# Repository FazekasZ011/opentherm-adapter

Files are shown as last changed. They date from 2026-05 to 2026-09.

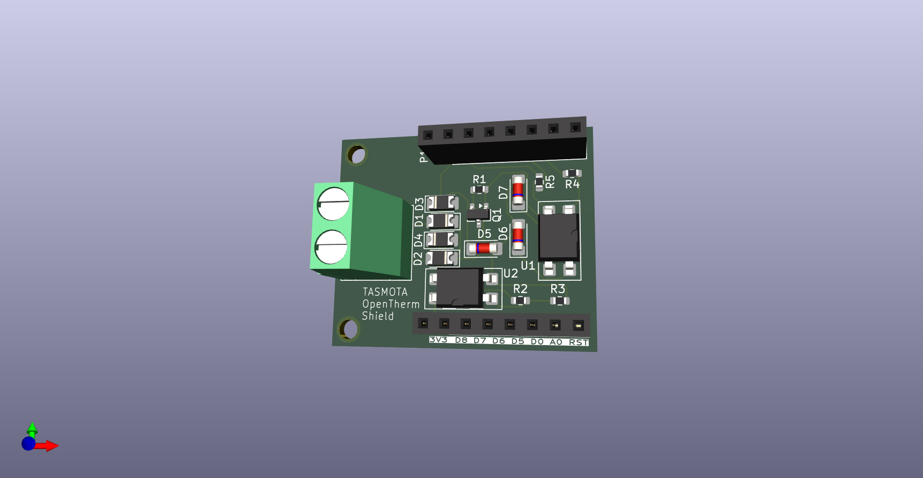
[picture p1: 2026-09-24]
KiCAD/opentherm shield.png

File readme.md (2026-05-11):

esphome - megvan
esphome builder kell még
esp-homebuildernél:
	- new device
	- new device setup
	- név bármi amit jónak találsz
- installation: 
	skip this step
	beállítod az eszközöd (esp8266)
	Install, majd cancel
	
létrejött az általad elnevezett XY.yaml egy kártyán látod az esphome felületén.

A kártyán válaszd az Edit-et.

Nagyon fontos:
az esp8266:
  board: esp01_1m eszköz helyére ezt írd: board: d1_mini

a captive_portal:
után ezt illeszd be:

# --- OPENTHERM ALAPBEÁLLÍTÁS ---
opentherm:
  in_pin: D2  # Wemos D2
  out_pin: D1 # Wemos D1

# --- SZENZOROK (Adatgyűjtés a kazánból) ---
sensor:
  - platform: opentherm
    t_boiler:
      name: "Kazán Előremenő Hőmérséklet"
    t_ret:
      name: "Visszatérő Hőmérséklet"
    
    # rel_mod_lvl helyett rel_mod_level-t kér:
    rel_mod_level: 
      name: "Kazán Aktuális Moduláció"
      unit_of_measurement: "%"
    
    # pressure helyett ch_pressure-t kér:
    ch_pressure: 
      name: "Rendszernyomás"
      unit_of_measurement: "bar"
      
    t_outside:
      name: "Kazán által érzékelt külső hőm"

# --- VEZÉRLÉS (Ezeket fogja a PID állítani a HA-ból) ---
number:
  - platform: opentherm
    # setpoint_temperature helyett t_set
    t_set:
      name: "Fűtési víz alapjel (CH Setpoint)"
      initial_value: 40
      min_value: 20
      max_value: 75
      step: 0.5
    
    # hot_water_setpoint_temperature helyett t_dhw_set
    t_dhw_set:
      name: "Melegvíz alapjel (DHW Setpoint)"
      initial_value: 45
      min_value: 35
      max_value: 65
      step: 1

# --- ÁLLAPOTJELZŐK (Diagnosztika) ---
binary_sensor:
  - platform: opentherm
    flame_on:
      name: "Gázláng"
    # central_heating_active helyett ch_active
    ch_active:
      name: "Fűtés aktív"
    # hot_water_active helyett dhw_active
    dhw_active:
      name: "Melegvíz készítés aktív"
    # fault helyett flame_fault vagy fault_indication (a logod flame_fault-ot sugall)
    flame_fault:
      name: "Kazán Hiba"
    diagnostic_indication:
      name: "Szerviz jelzés"

# --- KAPCSOLÓK ---
switch:
  - platform: opentherm
    ch_enable:
      name: "Fűtés Engedélyezése"
    dhw_enable:
      name: "Melegvíz Engedélyezése"

majd mentsd
utána a kártyán a 3 pöttynél válaszd az installt.
majd kábellel össze kell kötnöd a géped a wemossal.
válaszd a Plug into this computer-t
itt kiválasztod a COM-portot ahol az eszköz van. 
vársz és jó lesz.

Azt majd nézd meg, hogy a Secret nevű fájl létre jött-e mikor az esphomebuildert megcsináltad.

Ha megakadsz írj.

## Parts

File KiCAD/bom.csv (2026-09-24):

Designator | Footprint | Quantity | Value | LCSC Part #
D1, D2, D3, D4 | 1206 | 4 | 1N4148W
D5 | D_MiniMELF | 1 | BZV55B4V7
D6 | D_MiniMELF | 1 | BZV55B15
D7 | D_MiniMELF | 1 | BZV55B4V3
J1 | TerminalBlock_Phoenix_MKDS-1,5-2_1x02_P5.00mm_Horizontal | 1 | Screw_Terminal_01x02
P1, P2 | PinSocket_1x08_P2.54mm_Vertical | 2 | Conn_01x08_Pin
Q1 | SOT-23 | 1 | BC858
R1, R4 | 0603 | 2 | 330
R2 | 0603 | 1 | 220
R3 | 0603 | 1 | 100
R5 | 0603 | 1 | 1,5k
U1, U2 | DIP-4_W7.62mm_SMDSocket_SmallPads | 2 | PC817

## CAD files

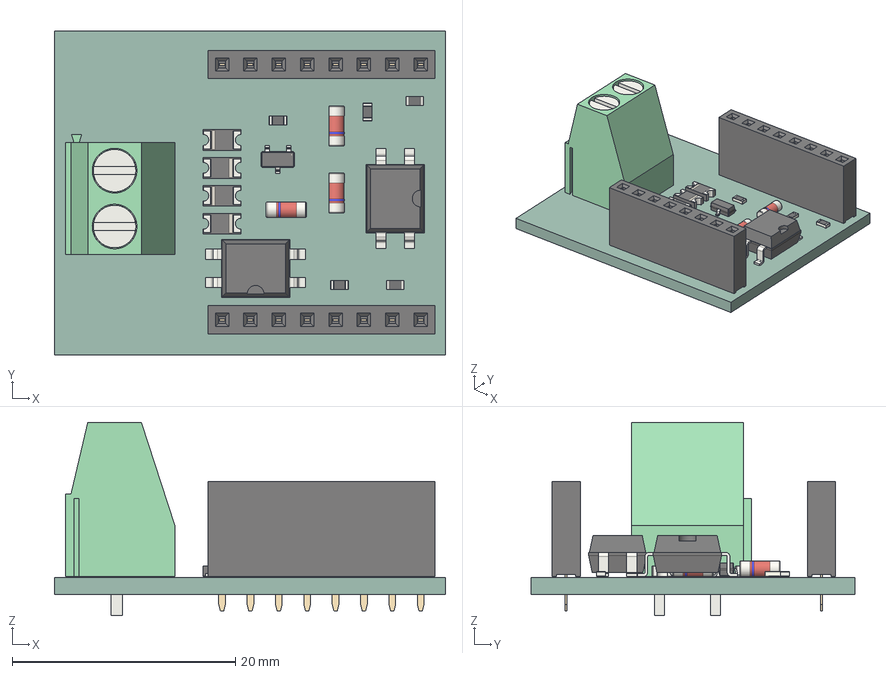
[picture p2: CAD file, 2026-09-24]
KiCAD/opentherm shield.step
35.0 x 29.0 x 17.3 mm
R_0603_1608Metric x 5
PinSocket_1x08_P2.54mm_Vertical x 2
DIP-4_W7.62mm_SMDSocket x 2
D_1206_3216Metric x 4
TerminalBlock_Phoenix_MKDS-1,5-2_1x02_P5.00mm_Horizontal
SOT-23
D_MiniMELF x 3
opentherm shield_PCB

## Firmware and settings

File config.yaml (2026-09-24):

  - platform: smart_thermostat
    name: "Fűtés_PID"
    unique_id: nappali_futes
    heater: switch.futes_ot_futes_engedelyezese
    target_sensor: sensor.XY
    outdoor_sensor: sensor.XY
    ac_mode: false
    # Szabályozási idők
    pwm: 0
    keep_alive: 00:01:00
    # PID beállítások (ezeket finomhangolnod kell!)
    kp: 10.0
    ki: 0.005
    kd: 250.0
    ke: 0.6
    # Modulációs üzemmódban ezeket minimalizáljuk, hogy a PID finoman állíthassa a számot
    min_cycle_duration: 00:00:00
    min_off_cycle_duration: 00:00:00
    # Kényelmi funkciók (Presets)
    precision: 0.1
    target_temp_step: 0.1
    min_temp: 17
    max_temp: 25
    away_temp: 18.0
    eco_temp: 21.0
    home_temp: 22.5
    comfort_temp: 23.5
    boost_temp: 24.5
    # Biztonság
    sensor_stall: 03:00:00
    output_safety: 10.0
    force_off_state: false
